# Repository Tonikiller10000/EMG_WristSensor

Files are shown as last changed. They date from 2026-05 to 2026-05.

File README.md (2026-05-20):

# EMG WRIST SENSOR

## Description (Deprecated)
<b>This is an electromiography sensor witch can detect muscular activity.</b> 

After making the PCB, when working at the software, I found about it`s limitations.
With EMG(electromiography) you can detect the voltage produced by the muscle contraction, meaning that for you to recive a signal, you need to stay with the muscle contracted. 
For exemple, closing your hand into a relaxed fist will not generate signals, unless you clench it, and you will recive a electrical voltage(mV).
When you feel a touch the senzation goes trouth the nerves(deeper) rather than muscles with a weeker signal detectable only with needles.
The input is not verry precise at all, and is verry tiering to stay with the muscle contracted for a long time.

> [!WARNING]
> !!! do not use needles... it can cause infections, blood electrolisis, metal poisoning and other health risks.

<br>

<table>
  <tr>
    <td>
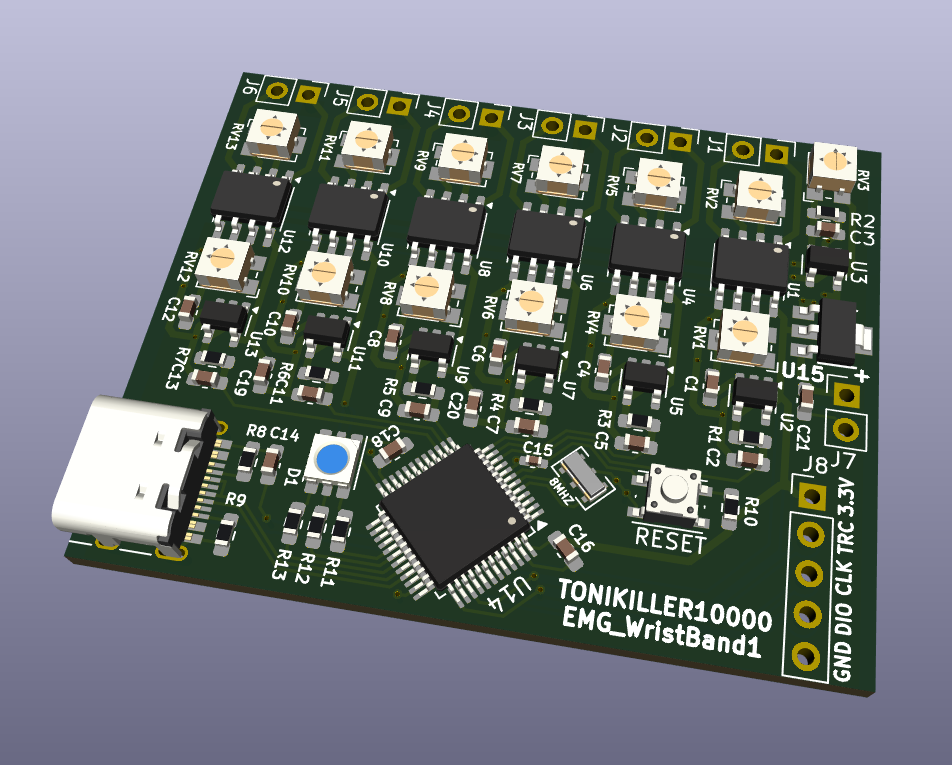
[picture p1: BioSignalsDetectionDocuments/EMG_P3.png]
3D Render
      
    </td>
    <td>
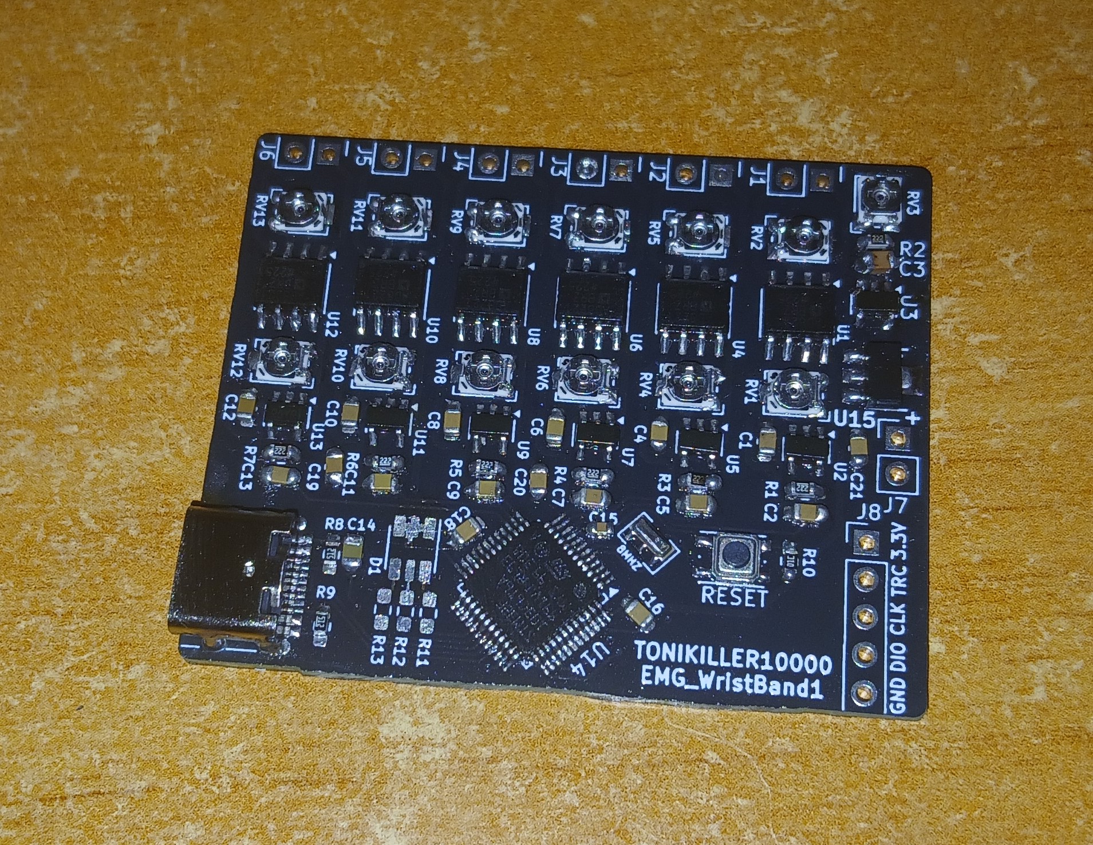
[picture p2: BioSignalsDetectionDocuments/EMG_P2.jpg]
Physical Board
      
    </td>
  </tr>
</table>

<table>
  <tr>
    <td>
        <p align="center">
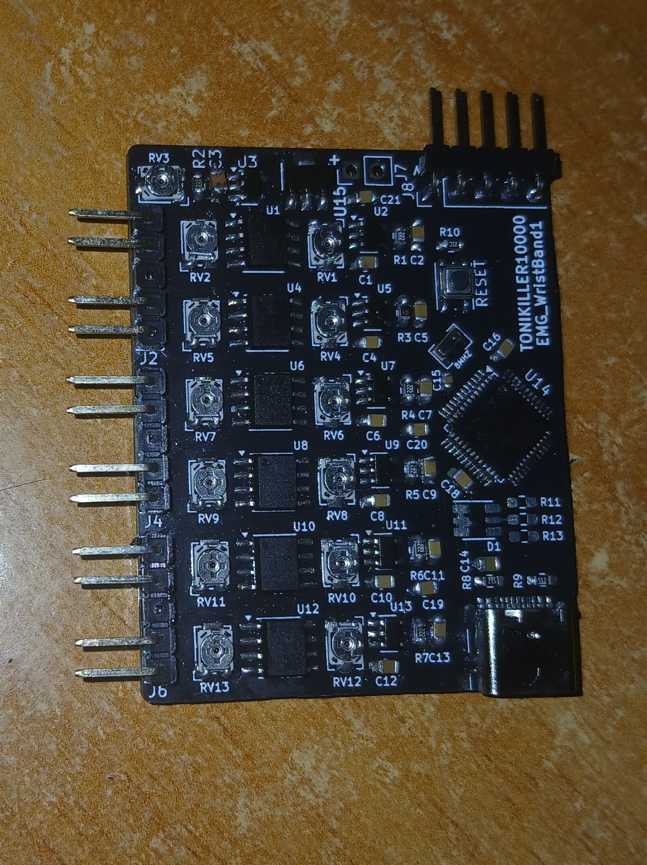
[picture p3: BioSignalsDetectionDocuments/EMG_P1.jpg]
            
        </p>
    </td>
    <td>
        <p align="center">
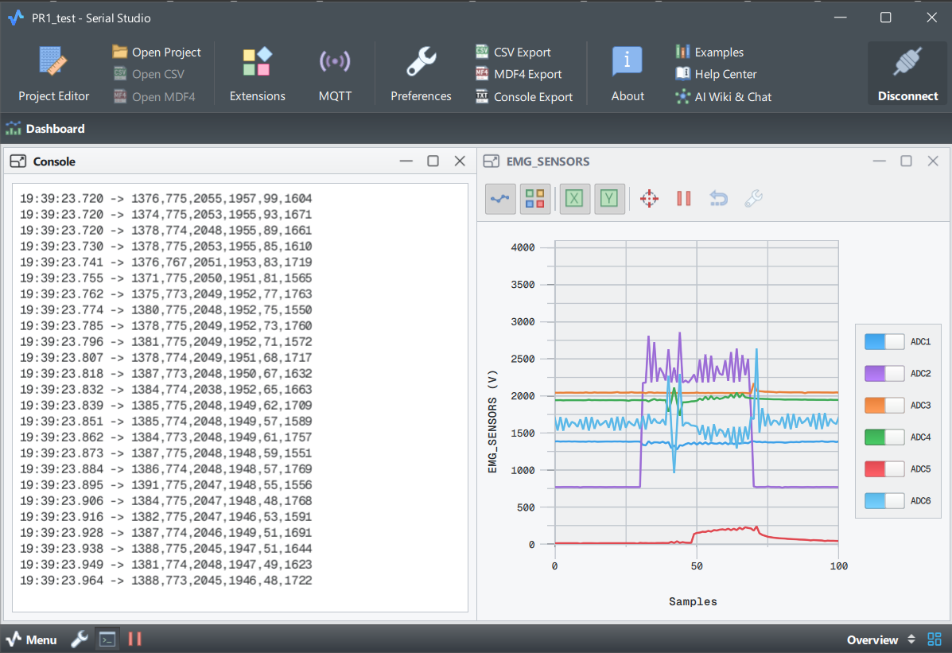
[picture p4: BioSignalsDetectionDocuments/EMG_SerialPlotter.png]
            
        </p>
    </td>
  </tr>
</table>

<table>
  <tr>
    <td valign="top" width="50%">
        <h3>Detected actions:</h3>
        <ul style="list-style-type: none; padding-left: 20px;">
            <li> relaxed palm</li>
            <li> tigth fist</li>
            <li> extended palm</li>
            <li> wrist movements up/down</li>
            <li> snap</li>
            <li> press</li>
            <li> other...</li>
        </ul>
        <br>
    </td>
    <td valign="top" width="50%">
        <h3> OBSERVATIONS:</h3>
        <ul style="list-style-type: none; padding-left: 20px;">
            <li> missing 1.5K resistor to USB_DP </li>
            <li> wrong RGB footprint</li>
            <li> try using flex pcb</li>
            <li> add FMG</li>
        </ul>
    </td>
  </tr>
</table>

<br>

## How it works & user instructions
- it has 6 pairs of diferential op amps each with a variable gain potentiometer. (it removes the 50-60hz noice from the grid) (all differential op amps have a common offset potentiometer)
- each output goes trouth an op amp with another gain potentiometer, and then It goes to an STM ADC pin
- then data is scanned and sent to the usb virtual port and can be read with a plotter
- when using it, connect the gnd to the skin so it dosen`t stay floating and produce electrostatis shots.
- !!! when programming with a STLINK, power it via the usb and disconnect the power pin from stlink to stm (keep the gnd common reference)
- use an [Online serial plotter](https://web-serial-plotter.atomic14.com/) or [Serial Studio Pro](https://serial-studio.com/) to see the USB data.
- More papers on the subject at [BioSignals Detection Documents folder](https://github.com/Tonikiller10000/EMG_WristSensor/tree/main/BioSignalsDetectionDocuments)

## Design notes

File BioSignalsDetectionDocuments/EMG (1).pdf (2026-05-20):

### BAND PASS FILTER DESIGN USING OP-AMP

THEORY:

A Band Pass Filter is a circuit which allows only particular band of frequencies to pass through it. This Pass band is mainly between the cut-off frequencies and they are fL and fH. Where fL is the lower cut-off frequency and fH is higher cut-off frequency. The center frequency is denoted by ‘fC’ and it is also called as resonant frequency or

peak frequency. The fL value must always be less than the value of fH. The pass band of the filter is nothing but the bandwidth. The gain of the filter is maximum at resonant or center frequency and this is referred as total pass band gain. First the signal will pass through the high pass filter, the output signal of this high

pass filter will tends to infinity and thus the signal which tends to infinity is given to the low pass filter at the end. This low pass filter will low pass the high frequency signal.When the High Pass Filter is cascaded with Low pass filter the simple Band Pass Filter is obtained. In order to realize this filter the order of the low pass and high pass circuits must be same. By cascading one first order low pass and high pass gives us the second order band pass filter and by cascading two first order low pass filters with two high pass filters forms a fourth order band pass filter. Due to this cascading the circuit produces a low value quality factor. The capacitor in the first order high pass filter will block any DC biasing from the input signal. SCHEMATIC DIAGRAM:

The circuit schematic of Band pass filter using op-amp in eSim is show in the figure below:

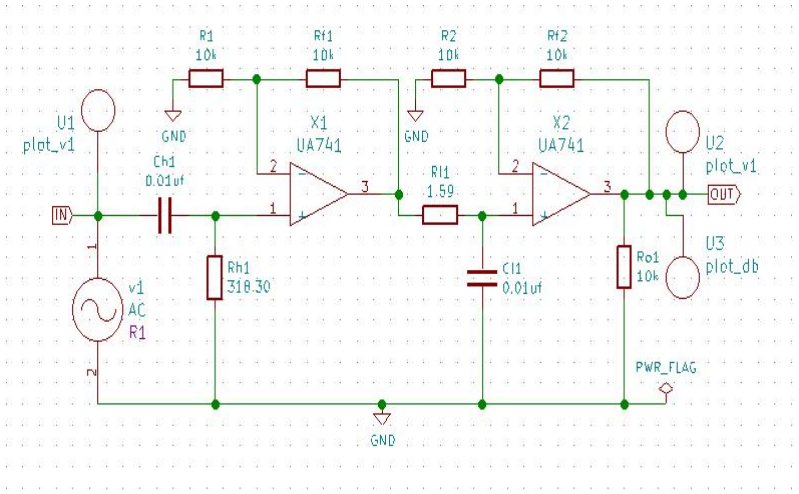
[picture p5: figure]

Figure 1: schematic diagram of Band pass filter using op-amp

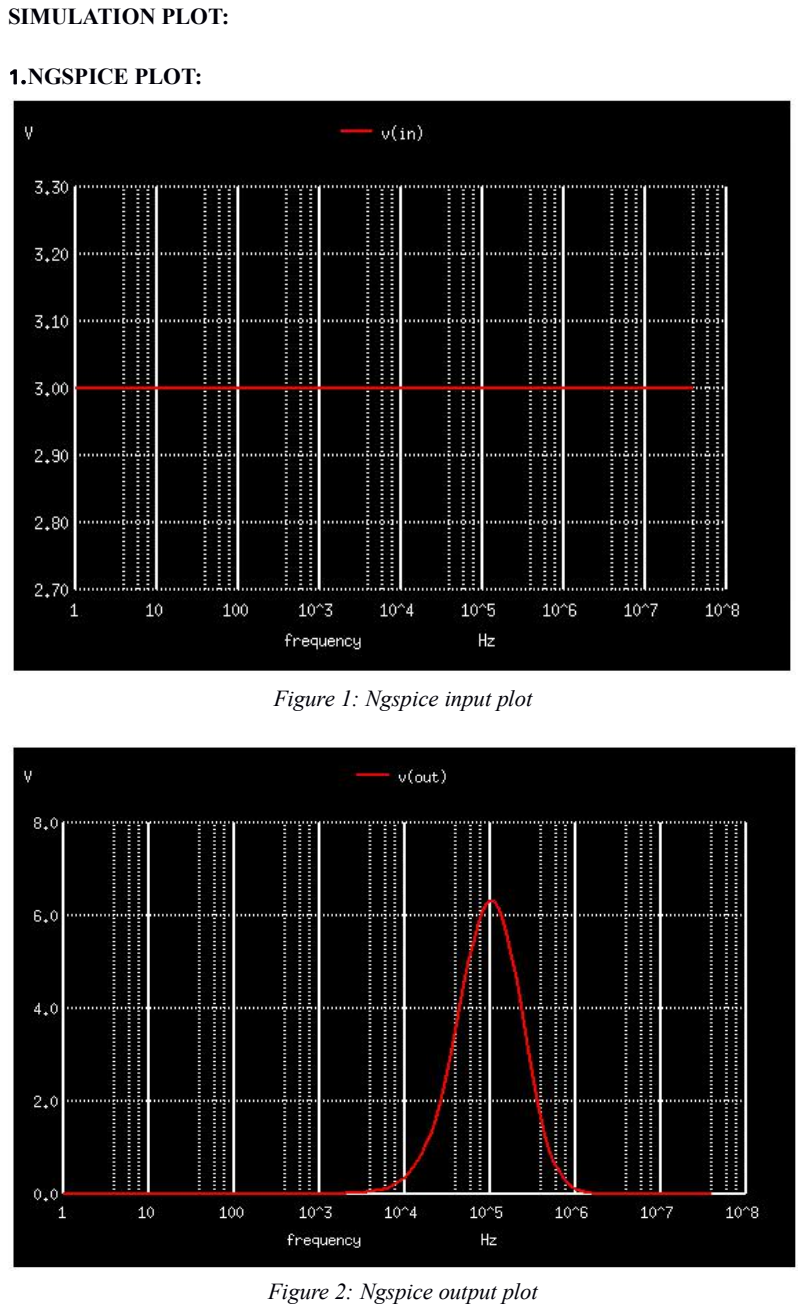
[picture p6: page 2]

SIMULATION PLOT:

1.NGSPICE PLOT:

Figure 1: Ngspice input plot

Figure 2: Ngspice output plot

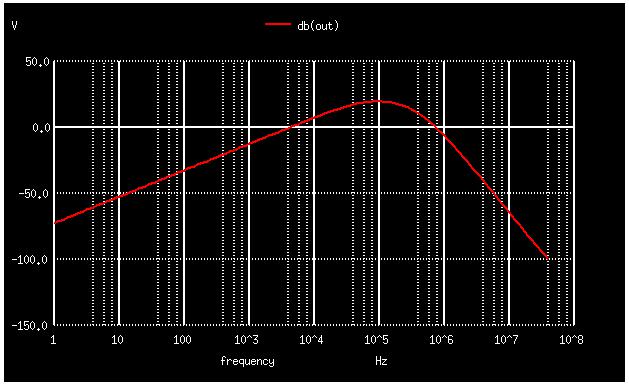
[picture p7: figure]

Figure 3: Ngspice frequency plot

CONCLUSION:

Thus we have studied the frequency response of the Band pass filter design using Op-Amp using eSim software and then simulated to get the appropriate waveforms. REFERENCES:

1. https://www.electronicshub.org/active-band-pass-filter/
2. http://www.circuitstoday.com/band-pass-filters

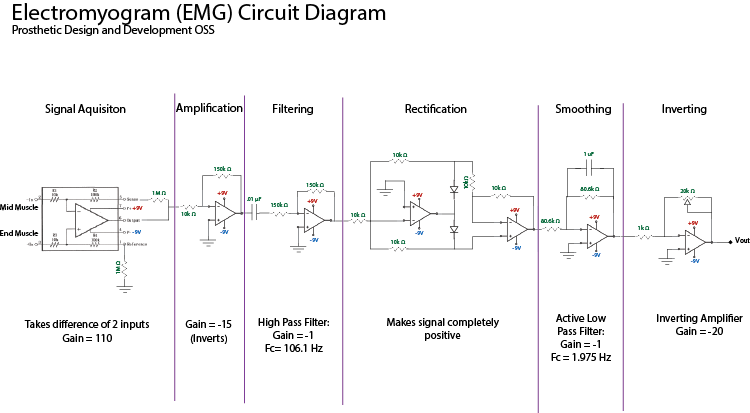
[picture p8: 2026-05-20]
BioSignalsDetectionDocuments/EMGGGGG (3).png

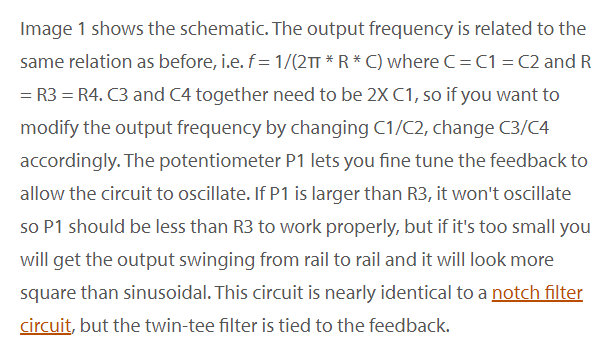
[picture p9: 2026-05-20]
BioSignalsDetectionDocuments/Screenshot 2024-10-06 211207.png

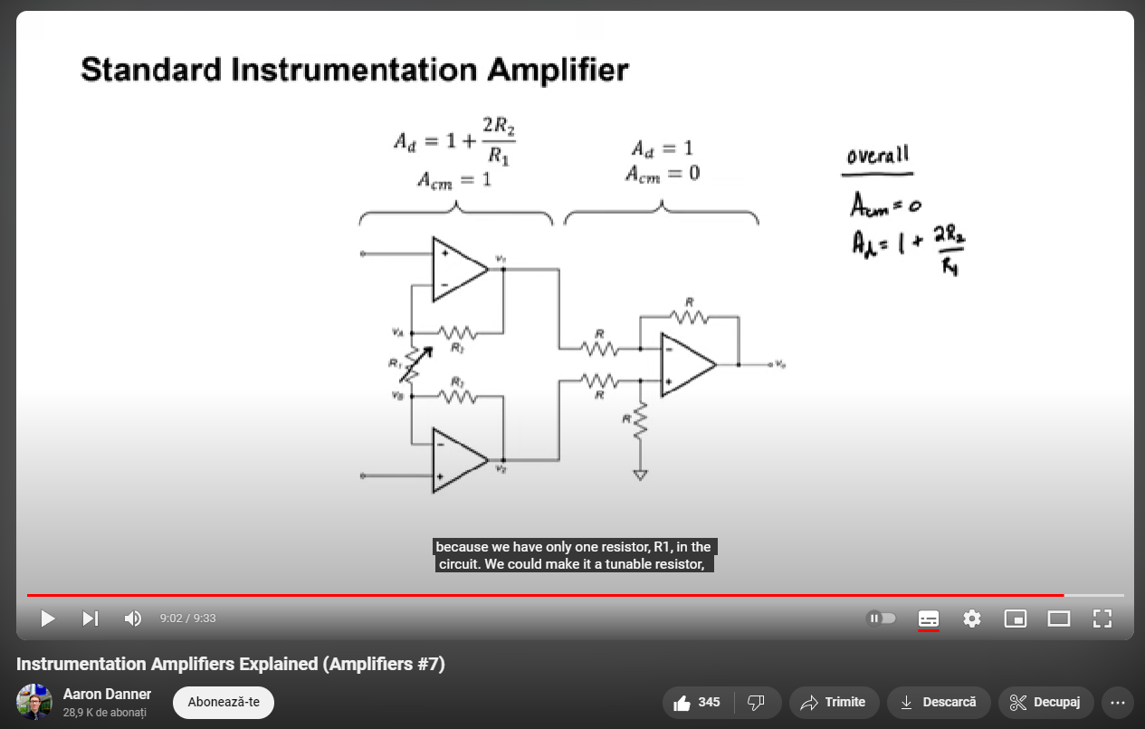
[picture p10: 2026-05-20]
BioSignalsDetectionDocuments/Screenshot 2024-10-07 215408.png

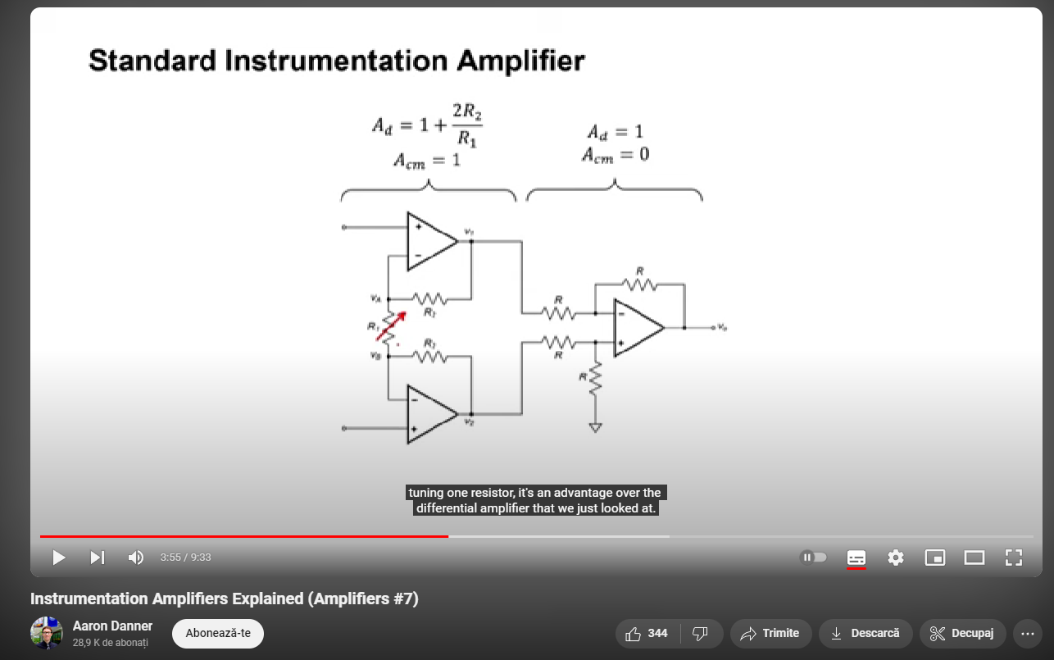
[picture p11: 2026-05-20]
BioSignalsDetectionDocuments/Screenshot 2024-10-07 215039.png

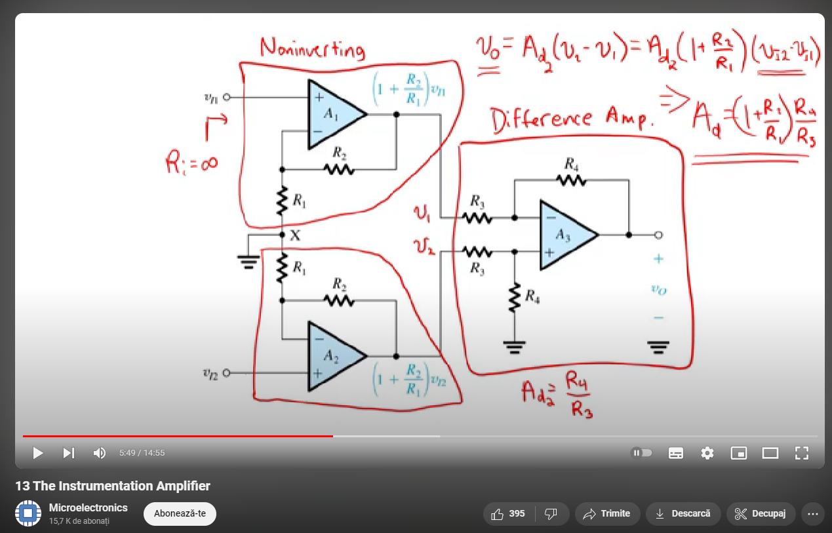
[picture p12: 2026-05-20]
BioSignalsDetectionDocuments/Screenshot 2024-10-07 214444.png

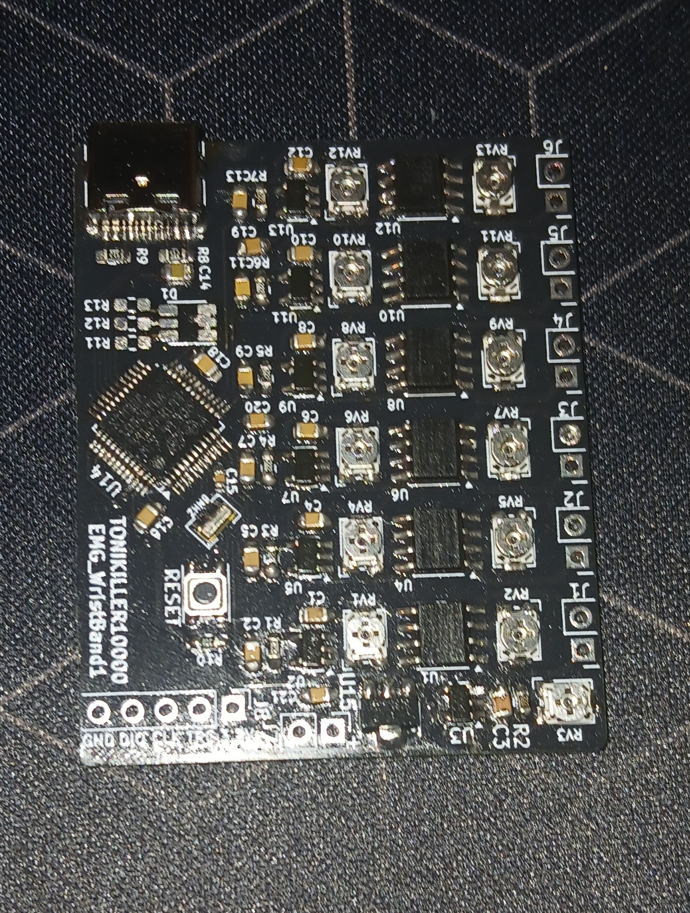
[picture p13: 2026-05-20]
BioSignalsDetectionDocuments/emga (1).jpg

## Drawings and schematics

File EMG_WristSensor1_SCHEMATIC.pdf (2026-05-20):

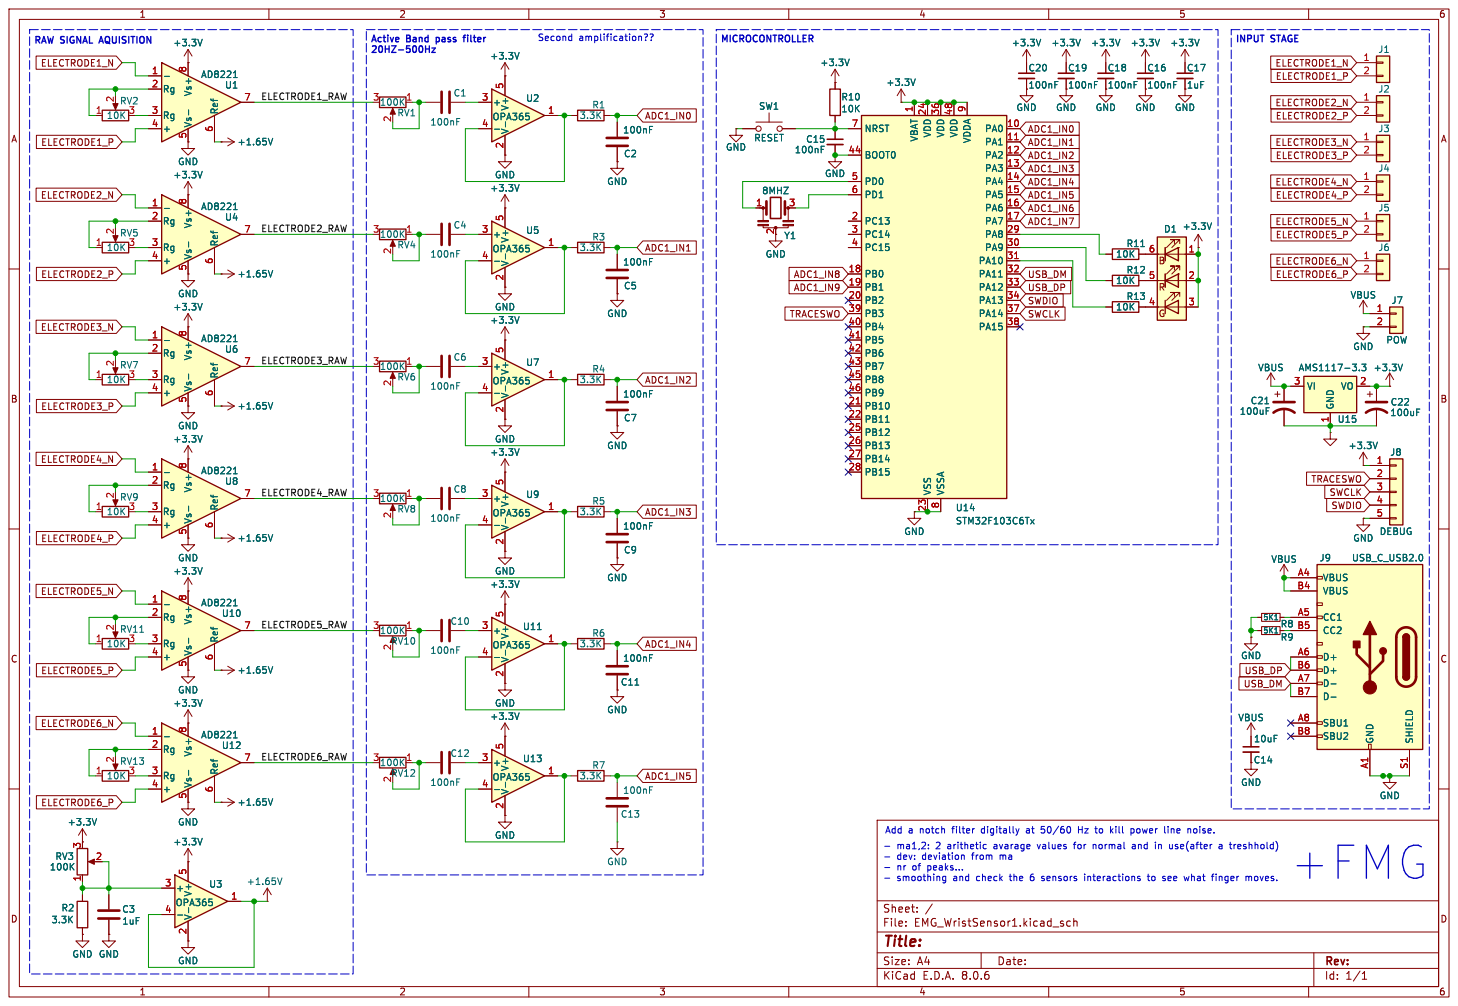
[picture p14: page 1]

1 PA0 10 PA1 11 PA2 12 PA3 13 PA4 14 PA5 15 PA6 16 PA7 17 PB0 18 PB1 19 PC13 2 PB2 20 PB10 21 PB11 22 VSS 23 VDD 24 PB12 25 PB13 26 PB14 27 PB15 28 PA8 29 PC14 3 PA9 30 PA10 31 PA11 32 PA12 33 PA13 34 VDD 36 PA14 37 PA15 38 PB3 39 PC15 4 PB4 40 PB5 41 PB6 42 PB7 43 BOOT0 44 PB8 45 PB9 46 VDD 48 PD0 5 PD1 6 NRST 7 VSSA

Id: 1/1 Title: File: EMG_WristSensor1.kicad_sch Sheet: /

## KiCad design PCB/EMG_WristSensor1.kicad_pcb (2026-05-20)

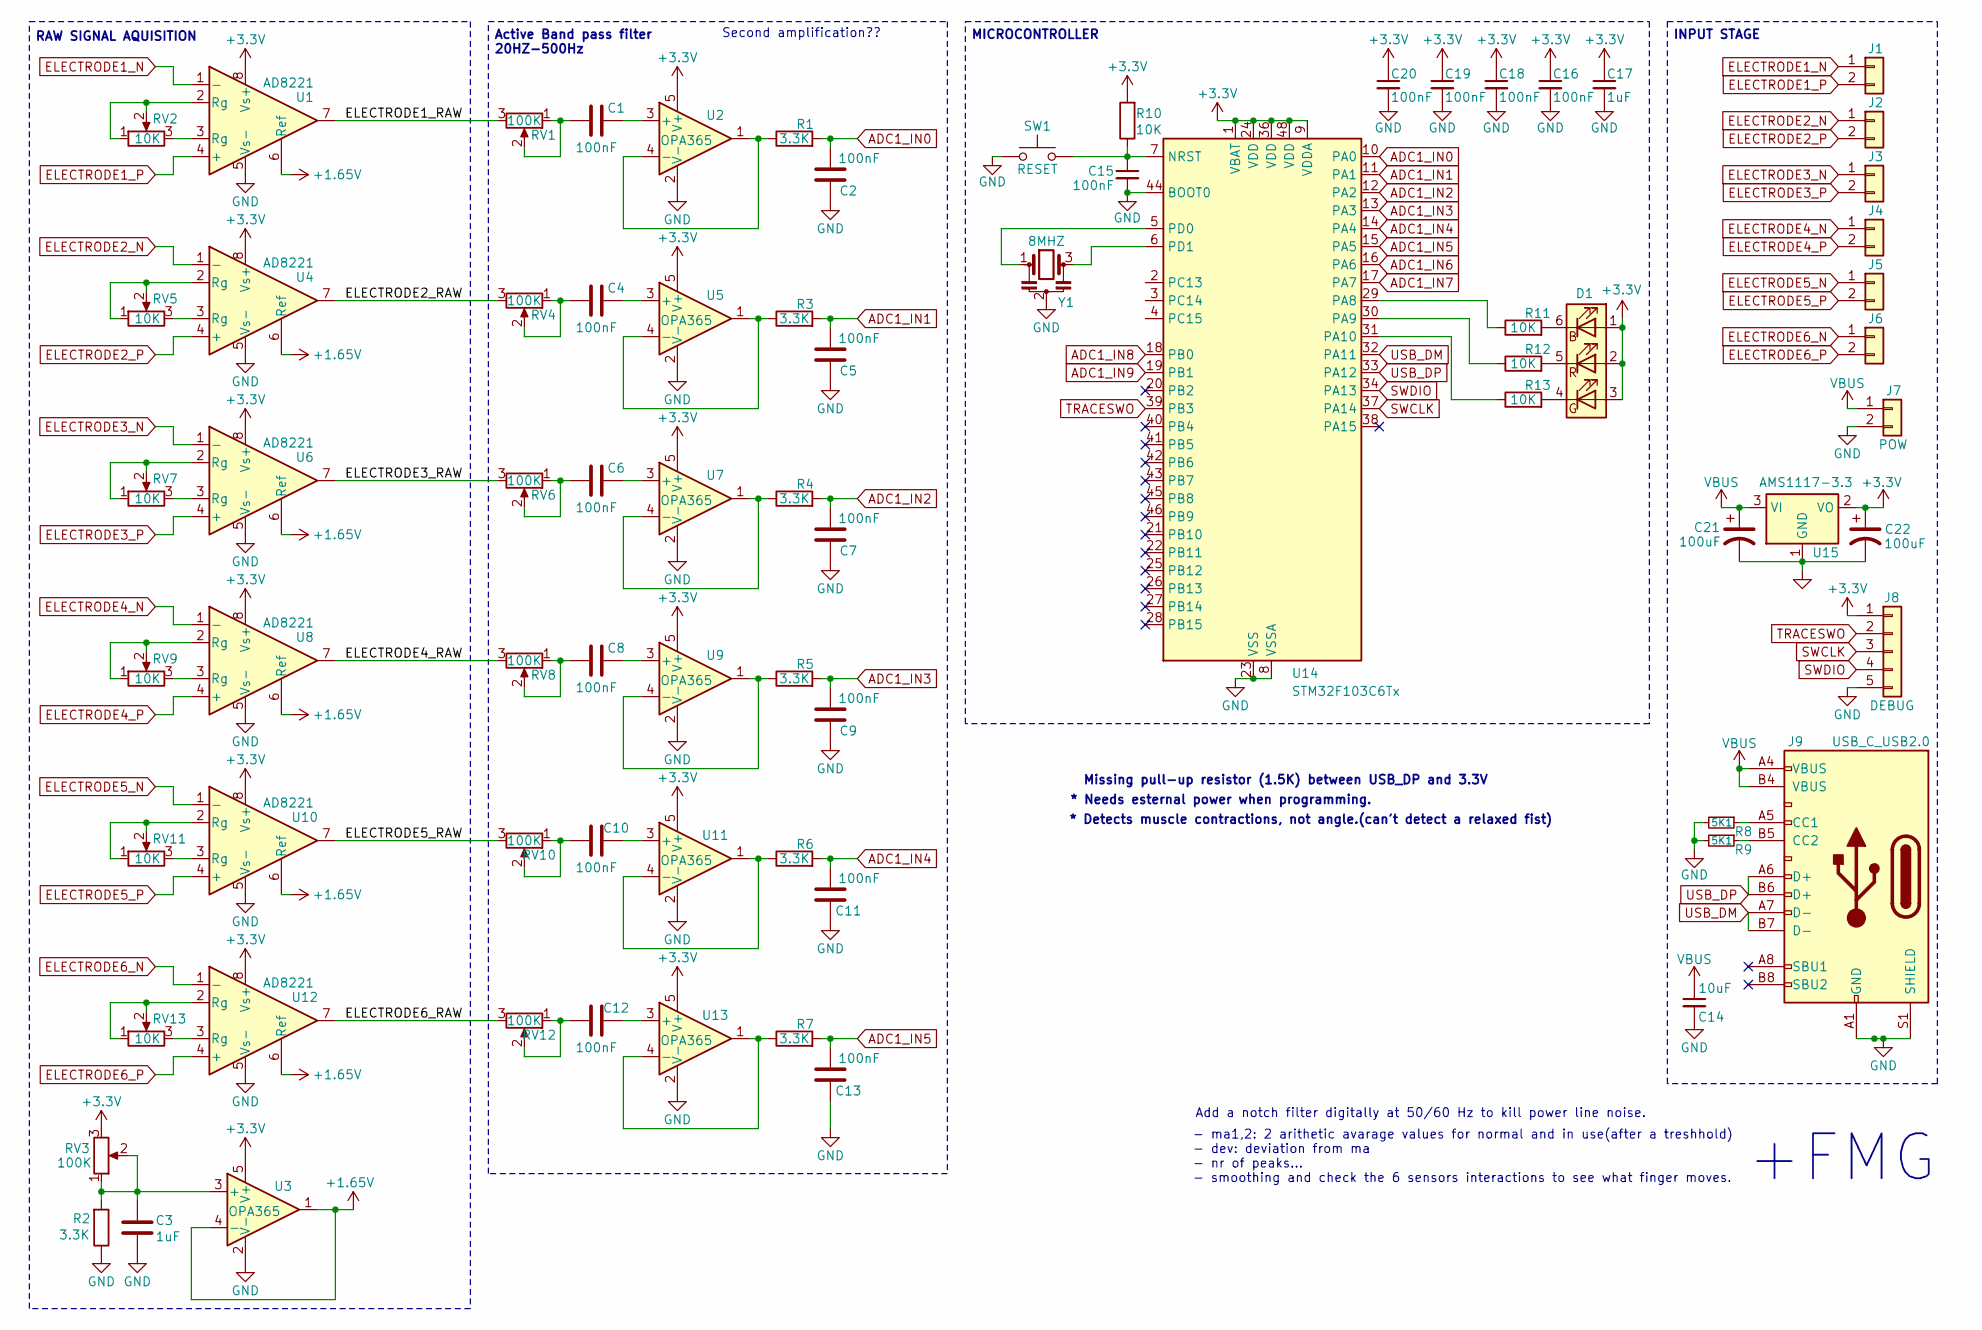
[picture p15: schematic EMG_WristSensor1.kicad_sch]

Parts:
C1, C2, C4, C5, C6, C7, C8, C9, C10, C11, C12, C13: 100nF; C_0603_1608Metric_Pad1.08x0.95mm_HandSolder
C3: 1uF; C_0603_1608Metric_Pad1.08x0.95mm_HandSolder
C14: 10uF
C15, C16, C18, C19, C20: 100nF; C_0402_1005Metric_Pad0.74x0.62mm_HandSolder
C17: 1uF; C_0402_1005Metric_Pad0.74x0.62mm_HandSolder
C21, C22: 100uF; C_1210_3225Metric_Pad1.33x2.70mm_HandSolder
D1: SMLVN6RGB; LED_ROHM_SMLVN6
J1, J2, J3, J4, J5, J6: Conn_01x02
J7: POW
J8: DEBUG
J9: USB_C_USB2.0
R1, R2, R3, R4, R5, R6, R7: 3.3K; R_0603_1608Metric_Pad0.98x0.95mm_HandSolder
R8, R9: 5K1; R_0402_1005Metric_Pad0.72x0.64mm_HandSolder
R10, R11, R12, R13: 10K; R_0603_1608Metric_Pad0.98x0.95mm_HandSolder
RV1, RV3, RV4, RV6, RV8, RV10, RV12: 100K; Potentiometer_Bourns_TC33X_Vertical
RV2, RV5, RV7, RV9, RV11, RV13: 10K; Potentiometer_Bourns_TC33X_Vertical
SW1: RESET
U1, U4, U6, U8, U10, U12: AD8221; SOP-8_3.9x4.9mm_P1.27mm
U2, U3, U5, U7, U9, U11, U13: OPA365; SOT-23-5
U14: STM32F103C6Tx; LQFP-48_7x7mm_P0.5mm
U15: AMS1117-3.3; SOT-223-3_TabPin2
Y1: 8MHZ

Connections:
+1.65V: U1.6 (Ref), U3.1, U3.4 (-), U4.6 (Ref), U6.6 (Ref), U8.6 (Ref), U10.6 (Ref), U12.6 (Ref)
+3.3V: C16.1, C17.1, C18.1, C19.1, C20.1, C22.1, D1.1 (BA), D1.2 (RA), D1.3 (GA), J8.1, R10.2, RV3.3, U1.8 (Vs+), U2.5 (V+), U3.5 (V+), U4.8 (Vs+), U5.5 (V+), U6.8 (Vs+), U7.5 (V+), U8.8 (Vs+), U9.5 (V+), U10.8 (Vs+), U11.5 (V+), U12.8 (Vs+), U13.5 (V+), U14.1 (VBAT), U14.9 (VDDA), U14.24 (VDD), U14.36 (VDD), U14.48 (VDD), U15.2 (VO)
/ELECTRODE1_RAW: RV1.3, U1.7
/ELECTRODE2_RAW: RV4.3, U4.7
/ELECTRODE3_RAW: RV6.3, U6.7
/ELECTRODE4_RAW: RV8.3, U8.7
/ELECTRODE5_RAW: RV10.3, U10.7
/ELECTRODE6_RAW: RV12.3, U12.7
ADC1_IN0: C2.1, R1.2, U14.10 (PA0)
ADC1_IN1: C5.1, R3.2, U14.11 (PA1)
ADC1_IN2: C7.1, R4.2, U14.12 (PA2)
ADC1_IN3: C9.1, R5.2, U14.13 (PA3)
ADC1_IN4: C11.1, R6.2, U14.14 (PA4)
ADC1_IN5: C13.1, R7.2, U14.15 (PA5)
ADC1_IN6: U14.16 (PA6)
ADC1_IN7: U14.17 (PA7)
ADC1_IN8: U14.18 (PB0)
ADC1_IN9: U14.19 (PB1)
ELECTRODE1_N: J1.1, U1.1 (-)
ELECTRODE1_P: J1.2, U1.4 (+)
ELECTRODE2_N: J2.1, U4.1 (-)
ELECTRODE2_P: J2.2, U4.4 (+)
ELECTRODE3_N: J3.1, U6.1 (-)
ELECTRODE3_P: J3.2, U6.4 (+)
ELECTRODE4_N: J4.1, U8.1 (-)
ELECTRODE4_P: J4.2, U8.4 (+)
ELECTRODE5_N: J5.1, U10.1 (-)
ELECTRODE5_P: J5.2, U10.4 (+)
ELECTRODE6_N: J6.1, U12.1 (-)
ELECTRODE6_P: J6.2, U12.4 (+)
GND: C2.2, C3.2, C5.2, C7.2, C9.2, C11.2, C13.2, C14.2, C15.2, C16.2, C17.2, C18.2, C19.2, C20.2, C21.2, C22.2, J7.2, J8.5, J9.A1 (GND), J9.B1 (GND), J9.S1 (SHIELD), R2.1, R8.2, R9.2, SW1.1, U1.5 (Vs-), U2.2 (V-), U3.2 (V-), U4.5 (Vs-), U5.2 (V-), U6.5 (Vs-), U7.2 (V-), U8.5 (Vs-), U9.2 (V-), U10.5 (Vs-), U11.2 (V-), U12.5 (Vs-), U13.2 (V-), U14.8 (VSSA), U14.23 (VSS), U14.35 (VSS), U14.44 (BOOT0), U14.47 (VSS), U15.1 (GND), Y1.2
unnamed: C1.1, RV1.1, RV1.2
unnamed: C4.1, RV4.1, RV4.2
unnamed: C6.1, RV6.1, RV6.2
unnamed: C8.1, RV8.1, RV8.2
unnamed: C10.1, RV10.1, RV10.2
unnamed: C12.1, RV12.1, RV12.2
unnamed: D1.6 (BK), R11.2
unnamed: D1.4 (GK), R13.2
unnamed: D1.5 (RK), R12.2
unnamed: J9.A5 (CC1), R8.1
unnamed: J9.B5 (CC2), R9.1
unnamed: RV2.1, RV2.2, U1.2 (Rg)
unnamed: RV2.3, U1.3 (Rg)
unnamed: RV5.1, RV5.2, U4.2 (Rg)
unnamed: RV5.3, U4.3 (Rg)
unnamed: RV7.1, RV7.2, U6.2 (Rg)
unnamed: RV7.3, U6.3 (Rg)
unnamed: RV9.1, RV9.2, U8.2 (Rg)
unnamed: RV9.3, U8.3 (Rg)
unnamed: RV11.1, RV11.2, U10.2 (Rg)
unnamed: RV11.3, U10.3 (Rg)
unnamed: RV13.1, RV13.2, U12.2 (Rg)
unnamed: RV13.3, U12.3 (Rg)
unnamed: C1.2, U2.3 (+)
unnamed: R1.1, U2.1, U2.4 (-)
unnamed: C3.1, R2.2, RV3.1, RV3.2, U3.3 (+)
unnamed: C4.2, U5.3 (+)
unnamed: R3.1, U5.1, U5.4 (-)
unnamed: C6.2, U7.3 (+)
unnamed: R4.1, U7.1, U7.4 (-)
unnamed: C8.2, U9.3 (+)
unnamed: R5.1, U9.1, U9.4 (-)
unnamed: C10.2, U11.3 (+)
unnamed: R6.1, U11.1, U11.4 (-)
unnamed: C12.2, U13.3 (+)
unnamed: R7.1, U13.1, U13.4 (-)
unnamed: C15.1, R10.1, SW1.2, U14.7 (NRST)
unnamed: R11.1, U14.29 (PA8)
unnamed: R12.1, U14.30 (PA9)
unnamed: R13.1, U14.31 (PA10)
unnamed: U14.5 (PD0), Y1.1
unnamed: U14.6 (PD1), Y1.3
SWCLK: J8.3, U14.37 (PA14)
SWDIO: J8.4, U14.34 (PA13)
TRACESWO: J8.2, U14.39 (PB3)
USB_DM: J9.A7 (D-), J9.B7 (D-), U14.32 (PA11)
USB_DP: J9.A6 (D+), J9.B6 (D+), U14.33 (PA12)
VBUS: C14.1, C21.1, J7.1, J9.A4 (VBUS), J9.B4 (VBUS), U15.3 (VI)

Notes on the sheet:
* Detects muscle contractions, not angle.(can't detect a relaxed fist)
- ma1,2: 2 arithetic avarage values for normal and in use(after a treshhold) - dev: deviation from ma - nr of peaks... - smoothing and check the 6 sensors interactions to see what finger moves.
Add a notch filter digitally at 50/60 Hz to kill power line noise.
+FMG
Second amplification??
MICROCONTROLLER
RAW SIGNAL AQUISITION
Missing pull-up resistor (1.5K) between USB_DP and 3.3V
Active Band pass filter 20HZ-500Hz
INPUT STAGE
* Needs esternal power when programming.

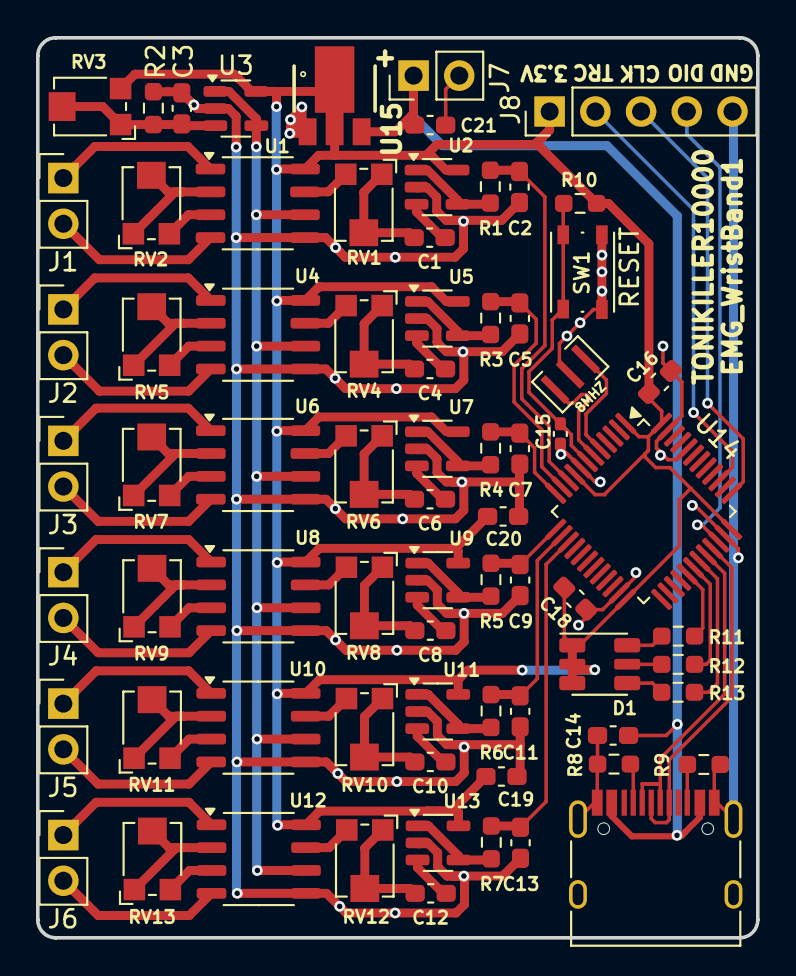
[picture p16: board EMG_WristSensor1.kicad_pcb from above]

Board: 2 copper layers, 40.0 x 50.0 mm, 73 parts (0 on the bottom side), 75 nets.

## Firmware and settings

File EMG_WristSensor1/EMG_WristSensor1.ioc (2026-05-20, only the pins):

Mcu.UserName=STM32F103C6Tx
PA0-WKUP.Signal=ADCx_IN0
PA1.Signal=ADCx_IN1
PA11.Signal=USB_DM
PA12.Signal=USB_DP
PA13.Signal=SYS_JTMS-SWDIO
PA14.Signal=SYS_JTCK-SWCLK
PA2.Signal=ADCx_IN2
PA3.Signal=ADCx_IN3
PA4.Signal=ADCx_IN4
PA5.Signal=ADCx_IN5
PA6.Signal=ADCx_IN6
PA7.Signal=ADCx_IN7
PB0.Signal=ADCx_IN8
PB1.Signal=ADCx_IN9
PB3.Signal=SYS_JTDO-TRACESWO
PD0-OSC_IN.Signal=RCC_OSC_IN
PD1-OSC_OUT.Signal=RCC_OSC_OUT
